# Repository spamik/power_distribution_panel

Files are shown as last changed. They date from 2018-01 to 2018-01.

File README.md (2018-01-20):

# Power distribution panel

Distribution panel for low voltage DC.

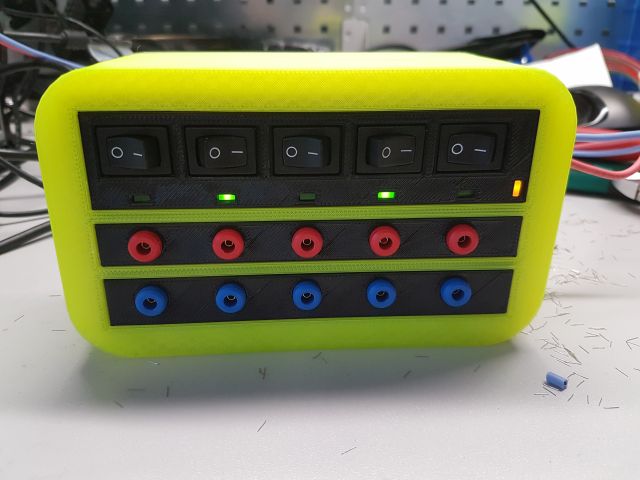
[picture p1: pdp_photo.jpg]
Panel photo


## Description
Panel has 5 "sockets" (banana plug pair). Each socket has own switch, LED indicator and fuse. Panel has also one central fuse. Ratings: PCB should be working fine up to 60V and 10A. It also depends on plugs, switches and components on PCB.

## PCB
In repository is source file for SprintLayout PCB editor. Also there is gerber export with excelon drilling data (should be named for seeed fusion). For PCB completion is needed: terminal blocks (10x flat type, 1x normal), 6 LEDs, 6 resistors (resistor params depend on desired voltage and LED params), 6 fuse holders.

## Box model
There are also STL files (and OpenSCAD source files) for box. Model is 3D printable (preffered PETG for box, front plate can be printed from ABS also fine). Box consist from front plate (plate with plugs, switches, etc), chassis and front box which locks everything in place. Chassis doesn't have back side, instead there are mounting holes (for screw mount to 38mm pitch "pegboard"). But it can be easily modified. Front box is lockes by 4 M3 screws and nuts.

## Assembly
- solder components on PCB (for LED soldering is better push LED in front plate and solder them in that position)
- mount switches and banana plugs into front plate
- attach wires to terminal blocks on PCB
- mount front plate on PCB (push it on LEDs)
- attach wires to switches and banana plugs
- insert desired fuses into fuse holders
- attach wires for input power to terminal block on pcb (take wires through hole in chassis)
- press 4 M3 nuts in prepared holes in chassis
- push front plate with PCB into chassis (groove in chassis should fit and support PCB)
- push front box over front plate and lock it with 4 M3 screws

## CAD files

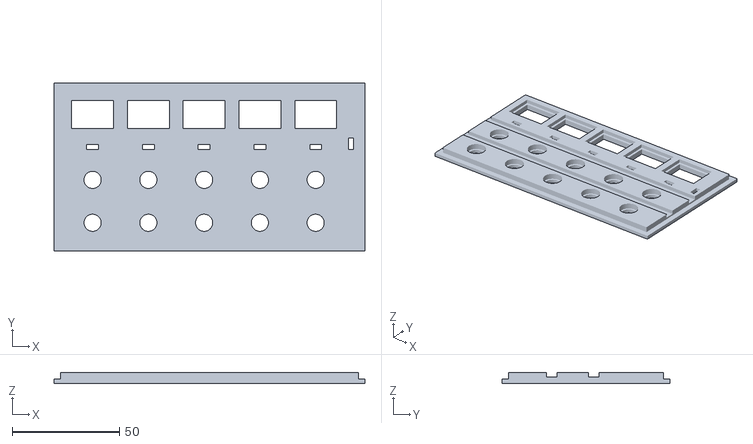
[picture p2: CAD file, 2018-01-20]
box_model/pdp_front_panel.stl
145.0 x 78.2 x 5.00

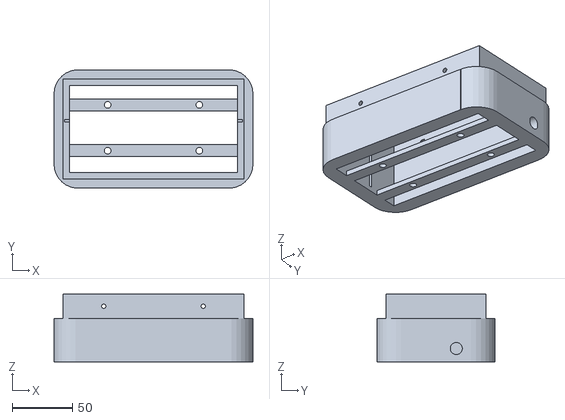
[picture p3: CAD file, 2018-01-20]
box_model/pdp_chassis_v2.stl
165.0 x 98.2 x 56.0

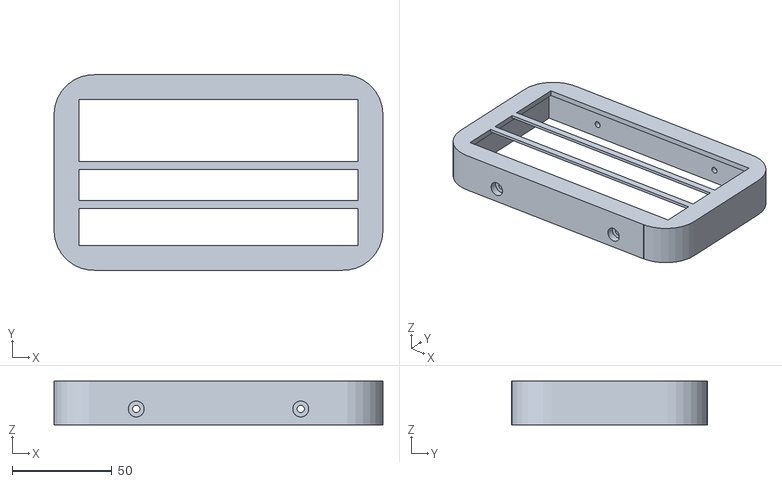
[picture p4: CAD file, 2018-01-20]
box_model/pdp_top_cover.stl
165.0 x 98.2 x 22.0

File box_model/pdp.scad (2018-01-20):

use <MCAD/boxes.scad>

// panel setup
section_width = 26;
section_height = 78.2;
sections = 5;
panel_thick = 5;
margin_left = 5;
margin_right = 10;
grid_size = 5;
grid_thick = 2;
construction_frame_thick = 3;
construction_frame_width = 3;

// switch setup
switch_body_width = 19.5;
switch_body_height = 13.2;
switch_frame_width = 22;
switch_frame_height = 16;
switch_frame_thick = 2;
switch_margin_top = 8;

// power LED setup
led_width = 5.5;
led_height = 2.5;
led_margin_top = 28.5;

// socket setup
socket_mount_hole = 8;
socket_frame_hole = 10.2;
socket_frame_thick = 3;
socket_vcc_margin_top = 40;
socket_gnd_margin_top = 60;

// box setup
box_frame = 10;
box_rounding = 20;
pcb_depth = 52;
back_depth = 4;
back_holder_width = 10;
pcb_thick = 2.3;
box_top_depth = 20;
frame_hole_dia = 3.6;
frame_hole_head = 8;
cable_hole_dia = 10;

// workbench setup
mountholes_pitch = 38;
mounthole_dia = 5.5;




// internal
total_width = margin_left + margin_right + sections*section_width;
box_depth = pcb_depth + back_depth;

//translate([total_width/-2, (section_height)/-2, box_depth/2-2]) front_plate();
//back_cover();
translate([0, 0, 20]) top_cover();

 box_width = total_width + 2*box_frame;
box_height = section_height + 2*box_frame;

cutout_width = total_width - 2*construction_frame_width;
cutout_height = section_height - 2*construction_frame_width;

module top_cover() {
    top_cover_depth = box_top_depth+construction_frame_thick-1;
    difference() {
        roundedBox([box_width, box_height, top_cover_depth], box_rounding, 10);
        
        // inner cutout
        translate([0, 0, top_cover_depth/-2+box_top_depth/2-1]) cube(size=[box_width-box_frame-5+1, box_height-box_frame-5+1, box_top_depth], center=true);
        
        // switch+LED cutout
        switch_section_size = (socket_vcc_margin_top - (socket_vcc_margin_top - led_margin_top - led_height)/2 - grid_size/2) - construction_frame_width + 1;
        translate([0, section_height/2 - switch_section_size/2 - construction_frame_width + 0.5, 0]) cube(size=[total_width - 2*construction_frame_width+1, switch_section_size, top_cover_depth+1], center=true);
        
        // vcc cutout
        vcc_section_size = (socket_gnd_margin_top - (socket_gnd_margin_top - socket_vcc_margin_top - socket_frame_hole)/2 - grid_size/2) - (socket_vcc_margin_top - (socket_vcc_margin_top - led_margin_top - led_height)/2 + grid_size/2) + 1;
        translate([0, section_height/-2 + vcc_section_size/2 + (section_height - socket_gnd_margin_top + (socket_gnd_margin_top - socket_vcc_margin_top - socket_frame_hole)/2 + grid_size/2 - 0.5), 0]) cube(size=[total_width - 2*construction_frame_width+1, vcc_section_size, top_cover_depth+1], center=true);
        
        // gnd cutout
        gnd_section_size = section_height - switch_section_size - vcc_section_size - 2*grid_size - 2*construction_frame_width + 3;
        translate([0, section_height/-2 + gnd_section_size/2 + construction_frame_width - 0.5]) cube(size=[total_width - 2*construction_frame_width+1, gnd_section_size, top_cover_depth+1], center=true);
        
        // grid cutout 
        translate([]) cube(size=[total_width - 2*construction_frame_width+1, section_height-2*construction_frame_width-2, top_cover_depth - grid_thick*2 +1], center=true);
        
        // frame holes
        translate([box_width/-4, box_height/2+1, -construction_frame_thick]) rotate(a=[90, 0, 0]) cylinder(d=frame_hole_dia, h=box_height+10, $fn=100);
        translate([box_width/4, box_height/2+1, -construction_frame_thick]) rotate(a=[90, 0, 0]) cylinder(d=frame_hole_dia, h=box_height+10, $fn=100);
        // screw head holes
        translate([box_width/-4, box_height/-2-1, -construction_frame_thick]) rotate(a=[-90, 0, 0]) cylinder(d=frame_hole_head, h=5, $fn=100);
        translate([box_width/4, box_height/-2-1, -construction_frame_thick]) rotate(a=[-90, 0, 0]) cylinder(d=frame_hole_head, h=5, $fn=100);
        translate([box_width/-4, box_height/2 + 1, -construction_frame_thick]) rotate(a=[90, 0, 0]) cylinder(d=frame_hole_head, h=5, $fn=100);
        translate([box_width/4, box_height/2 + 1, -construction_frame_thick]) rotate(a=[90, 0, 0]) cylinder(d=frame_hole_head, h=5, $fn=100);
    }
    //translate([box_width/-4, box_height/-2-1, -construction_frame_thick]) rotate(a=[-90, 0, 0]) cylinder(d=frame_hole_head, h=5, $fn=100);
}

module back_cover() {
   
    
    
    difference() {
        union() {
            difference() {
                roundedBox([box_width, box_height, box_depth], box_rounding, 10);
                
                // cutout whole box
                cube(size=[cutout_width, cutout_height, box_depth+2], center=true);
                
                
                // front plate cutout
                front_plate_cutout = panel_thick - construction_frame_thick + 1;
                translate([0, 0, front_plate_cutout/-2+box_depth/2+1]) cube(size=[total_width+1, section_height+1, front_plate_cutout], center=true);
            }
            
 
            // back holders
           translate([0, 20, box_depth/-2+back_depth/2]) cube(size=[box_width, back_holder_width, back_depth], center=true); 
            translate([0, 20-mountholes_pitch*1, box_depth/-2+back_depth/2]) cube(size=[box_width, back_holder_width, back_depth], center=true);
        }
        
        // pcb holder
        translate([0, section_height/2-led_margin_top-led_height-2.5/2, back_depth]) cube(size=[total_width+3, pcb_thick, box_depth], center=true);
        
        // cable hole
        translate([0, section_height/2-led_margin_top+led_height-2.5/2 + cable_hole_dia/2, box_depth/-2 + back_depth + cable_hole_dia/2+2]) rotate(a=[0, 90, 0]) cylinder(d=cable_hole_dia, h=box_width, $fn=100); 
        
        // mount holes
        translate([mountholes_pitch, 20, box_depth/-2-1]) cylinder(d=mounthole_dia, h=box_depth, $fn=100);
        translate([-mountholes_pitch, 20, box_depth/-2-1]) cylinder(d=mounthole_dia, h=box_depth, $fn=100);
        translate([mountholes_pitch, 20-mountholes_pitch*1, box_depth/-2-1]) cylinder(d=mounthole_dia, h=box_depth, $fn=100);
        translate([-mountholes_pitch, 20-mountholes_pitch*1, box_depth/-2-1]) cylinder(d=mounthole_dia, h=box_depth, $fn=100);
        
        // mount frame
        translate([0, 0, box_top_depth/-2+box_depth/2+0.01]) difference() {
            cube(size=[box_width+1, box_height+1, box_top_depth], center=true);
            cube(size=[box_width-box_frame-5, box_height-box_frame-5, box_top_depth+1], center=true);
    }
        // frame holes
        translate([box_width/-4, box_height/2+1, box_depth/2 - box_top_depth/2]) rotate(a=[90, 0, 0]) cylinder(d=frame_hole_dia, h=box_height+10, $fn=100);
        translate([box_width/4, box_height/2+1, box_depth/2 - box_top_depth/2]) rotate(a=[90, 0, 0]) cylinder(d=frame_hole_dia, h=box_height+10, $fn=100);
        // nut traps
        translate([box_width/-4, box_height/2-box_frame/2+5/2-box_frame/1.25, box_depth/2 - box_top_depth/2]) rotate(a=[90, 0, 0]) cylinder(r=5.5 / 2 / cos(180 / 6) + 0.05, h=50, $fn=6);
        translate([box_width/4, box_height/2-box_frame/2+5/2-box_frame/1.25, box_depth/2 - box_top_depth/2]) rotate(a=[90, 0, 0]) cylinder(r=5.5 / 2 / cos(180 / 6) + 0.05, h=50, $fn=6);
        translate([box_width/-4, box_height/-2 + box_frame+20/2+12.5, box_depth/2 - box_top_depth/2]) rotate(a=[90, 0, 0]) cylinder(r=5.5 / 2 / cos(180 / 6) + 0.05, h=22, $fn=6);
        translate([box_width/4, box_height/-2 + box_frame+20/2+12.5, box_depth/2 - box_top_depth/2]) rotate(a=[90, 0, 0]) cylinder(r=5.5 / 2 / cos(180 / 6) + 0.05, h=22, $fn=6);
    
        
    }
    
    
}

module front_plate() {
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
